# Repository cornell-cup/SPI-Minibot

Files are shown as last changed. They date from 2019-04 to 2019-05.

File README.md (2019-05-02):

# SPI-Minibot
For SPI communication between Pi and Arduino (should support up to 4 devices) with new PCB design

HOW TO RUN:
You type into terminal
1. cd SPI-Minibot
2. python -c 'import SPI_test; SPI_test.claw()'

NOTE: change .claw() function to whatever function you want to run
(ex. shoulder(), left(),right(),fwd(),back(),armL() [stepper], armR()[also stepper]

SPI_1.ino refers to top arduino (Closest to the raspberry pi)
SPI_A2.ino referes to bottom arduino (closest to battery)

When loading Arduino (.ino) programs:
Connect USB to serial (USB to jumper cables) and run SPI_1.ino on the top arduino
and then connect the cable to the bottom arduino and run SPI_A2.ino on the bottom one. 

When cloning this Repo (If not already loaded on the Pi):
1. Make sure you have SPI enabled (easiest way is through the GUI in NOOBS so you can just go to configuration and enable)
      Otherwise on terminal do ifconfig and select the option for serial (I think option 6, will verify later)
2. Make sure you have SCL,SDA,CE0, and CE1 wires all connected

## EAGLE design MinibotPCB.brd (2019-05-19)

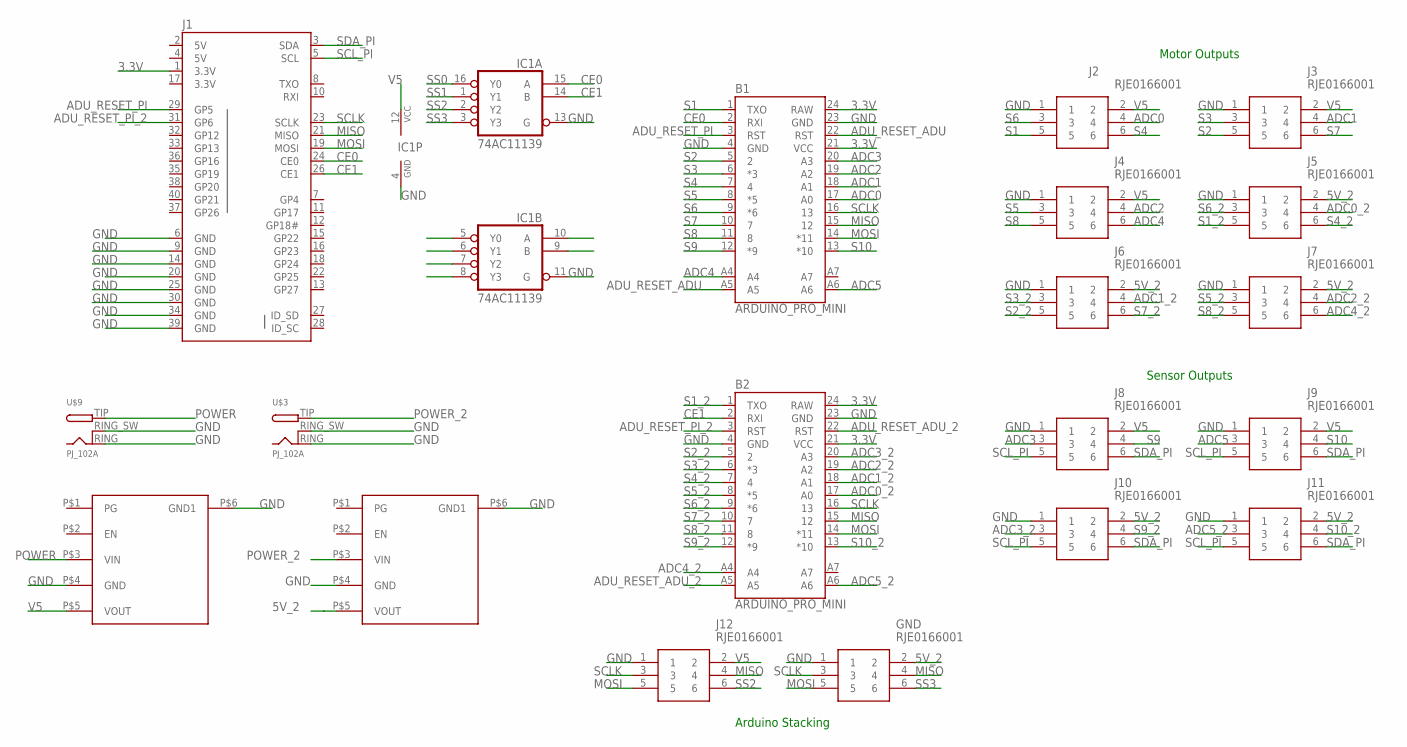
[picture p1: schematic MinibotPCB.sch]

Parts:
B1, B2: ARDUINO_PRO_MINI
GND: RJE0166001; RJE0166001_1
IC1: 74AC11139; DIL16
J1: RASPBERRYPI-40-PIN-GPIO_PTH_NO_SHROUD; 2X20
J2, J3, J4, J5, J6, J7, J8, J9, J10, J11, J12: RJE0166001; RJE0166001_1
U$1, U$2: D24V22F5
U$3, U$9: PJ_102A; PJ-102A

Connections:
3.3V: B1.21 (VCC), B1.24 (RAW), B2.21 (VCC), B2.24 (RAW), J1.1 (3.3V), J1.17 (3.3V)
5V: J1.2 (5V), J1.4 (5V)
5V_2: GND.2, J5.2, J6.2, J7.2, J10.2, J11.2, U$1.P$5 (VOUT)
ADC0: B1.17 (A0), J2.4
ADC0_2: B2.17 (A0), J5.4
ADC1: B1.18 (A1), J3.4
ADC1_2: B2.18 (A1), J6.4
ADC2: B1.19 (A2), J4.4
ADC2_2: B2.19 (A2), J7.4
ADC3: B1.20 (A3), J8.3
ADC3_2: B2.20 (A3), J10.3
ADC4: B1.A4, J4.6
ADC4_2: B2.A4, J7.6
ADC5: B1.A6, J9.3
ADC5_2: B2.A6, J11.3
ADU_RESET_ADU: B1.22 (RST), B1.A5
ADU_RESET_ADU_2: B2.22 (RST), B2.A5
ADU_RESET_PI: B1.3 (RST), J1.29 (GP5)
ADU_RESET_PI_2: B2.3 (RST), J1.31 (GP6)
CE0: B1.2 (RXI), IC1.15 (A), J1.24 (CE0)
CE1: B2.2 (RXI), IC1.14 (B), J1.26 (CE1)
GND: B1.4 (GND), B1.23 (GND), B2.4 (GND), B2.23 (GND), GND.1, IC1.4 (GND), IC1.11 (G), IC1.13 (G), J1.6 (GND), J1.9 (GND), J1.14 (GND), J1.20 (GND), J1.25 (GND), J1.30 (GND), J1.34 (GND), J1.39 (GND), J2.1, J3.1, J4.1, J5.1, J6.1, J7.1, J8.1, J9.1, J10.1, J11.1, J12.1, U$1.P$4 (GND), U$1.P$6 (GND1), U$2.P$4 (GND), U$2.P$6 (GND1), U$3.RING (GND), U$3.RING_SW (GNDBREAK), U$9.RING (GND), U$9.RING_SW (GNDBREAK)
MISO: B1.15 (12), B2.15 (12), GND.4, J1.21 (MISO), J12.4
MOSI: B1.14 (*11), B2.14 (*11), GND.5, J1.19 (MOSI), J12.5
POWER: U$2.P$3 (VIN), U$9.TIP (PWR)
POWER_2: U$1.P$3 (VIN), U$3.TIP (PWR)
S1: B1.1 (TXO), J2.5
S1_2: B2.1 (TXO), J5.5
S2: B1.5 (2), J3.5
S2_2: B2.5 (2), J6.5
S3: B1.6 (*3), J3.3
S3_2: B2.6 (*3), J6.3
S4: B1.7 (4), J2.6
S4_2: B2.7 (4), J5.6
S5: B1.8 (*5), J4.3
S5_2: B2.8 (*5), J7.3
S6: B1.9 (*6), J2.3
S6_2: B2.9 (*6), J5.3
S7: B1.10 (7), J3.6
S7_2: B2.10 (7), J6.6
S8: B1.11 (8), J4.5
S8_2: B2.11 (8), J7.5
S9: B1.12 (*9), J8.4
S9_2: B2.12 (*9), J10.4
S10: B1.13 (*10), J9.4
S10_2: B2.13 (*10), J11.4
SCLK: B1.16 (13), B2.16 (13), GND.3, J1.23 (SCLK), J12.3
SCL_PI: J1.5 (SCL), J8.5, J9.5, J10.5, J11.5
SDA_PI: J1.3 (SDA), J8.6, J9.6, J10.6, J11.6
SS0: IC1.16 (Y0)
SS1: IC1.1 (Y1)
SS2: IC1.2 (Y2), J12.6
SS3: GND.6, IC1.3 (Y3)
V5: IC1.12 (VCC), J2.2, J3.2, J4.2, J8.2, J9.2, J12.2, U$2.P$5 (VOUT)

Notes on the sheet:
Arduino Stacking
Sensor Outputs
Motor Outputs

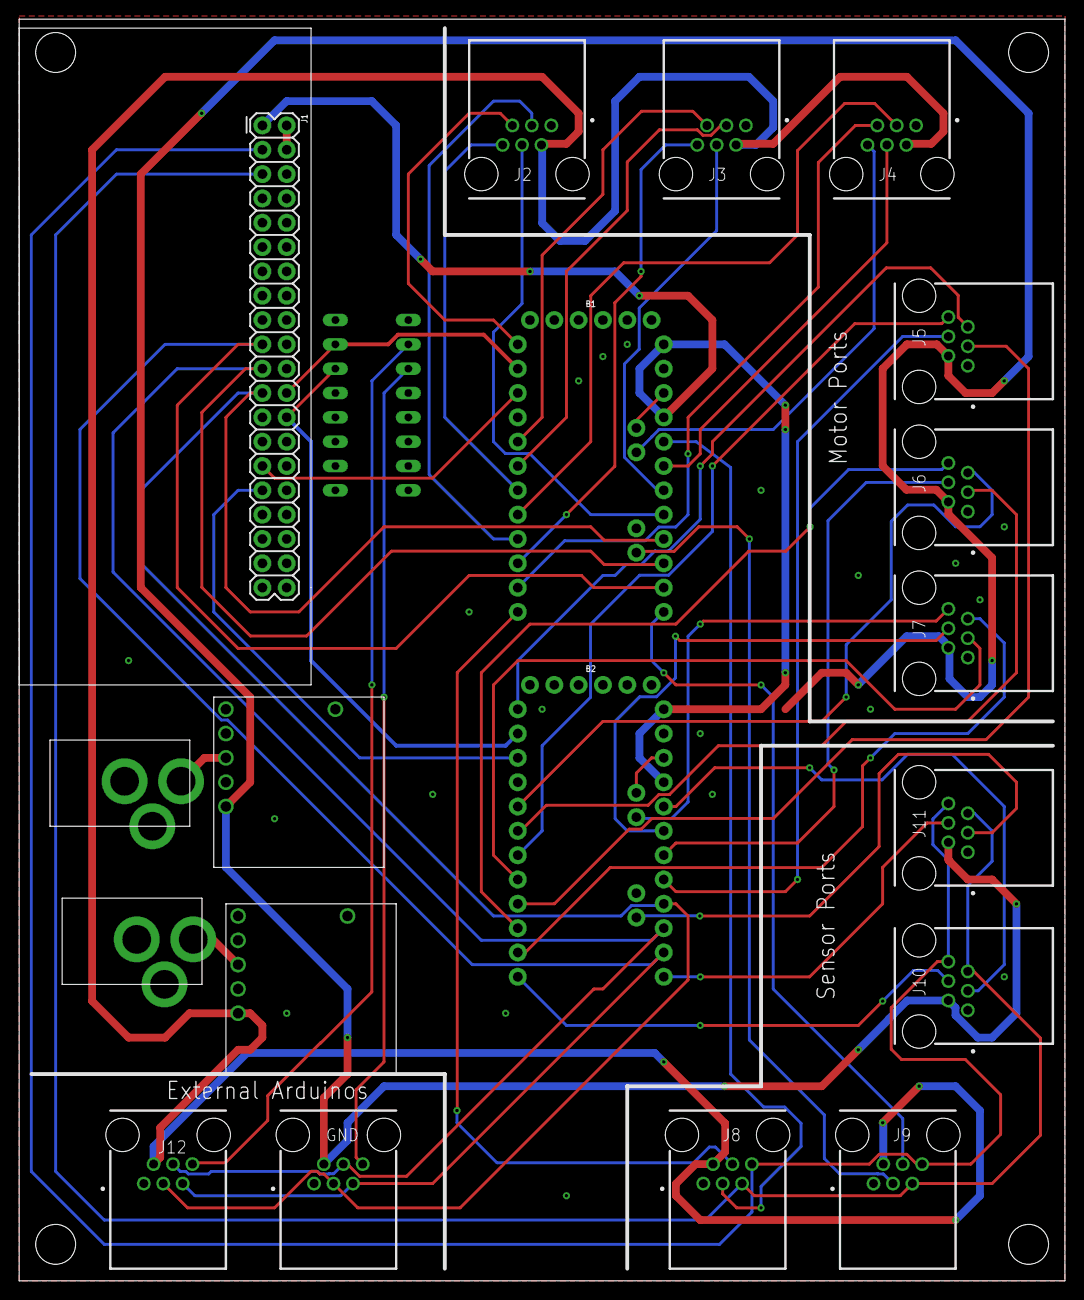
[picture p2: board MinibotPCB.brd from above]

Board: 2 copper layers, 109.2 x 131.8 mm, 20 parts (1 on the bottom side), 52 nets.

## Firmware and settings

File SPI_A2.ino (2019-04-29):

#include <SPI.h>
#include <Servo.h>
#include <Stepper.h>

const int stepsPerRevolution = 2038;// change this to fit the number of steps per revolution
// for your motor

// initialize the stepper library on pins 8 through 11:

Stepper stepper(stepsPerRevolution, A1, 7, 3, 2);
Stepper rstepper(stepsPerRevolution, 2,3,7,A1);
Stepper stepper2(stepsPerRevolution, A2, A4, 5, 8);
Stepper rstepper2(stepsPerRevolution, 8,5,A4,A2);

int stepCount = 0;         // number of steps the motor has taken

Servo myservo;

int val;
char buff [50];
volatile byte indx;
volatile boolean process;
//int  interruptPin = 10;
//int motorPin1 = 2;
//int motorPin2 = 3;
//int motorPin3 = 8;
//int motorPin4 = 5;
void setup() {
  // put your setup code here, to run once:
  Serial.begin(115200);
  myservo.attach(6);//servo pin
  pinMode(MISO,OUTPUT); //init spi
  pinMode(3,OUTPUT);
  //Init DC pins
//  pinMode(motorPin1, OUTPUT);
//  pinMode(motorPin2, OUTPUT);
//  pinMode(motorPin3, OUTPUT);
//  pinMode(motorPin4, OUTPUT);
  pinMode(20,OUTPUT);
  pinMode(22,OUTPUT);
  SPCR |= bit (SPE); // slave control register
  indx = 0; //buffer empty
  process = false;
  
//  pinMode(interruptPin,INPUT);
//  int val = digitalRead(interruptPin);
  //if (!val)
    //Serial.println ("wtf");
  delay(1000);
  SPI.attachInterrupt();
 // attachInterrupt(digitalPinToInterrupt(interruptPin), tester, LOW); //enable interrupt
  //val = 1;
  //Serial.print(val);
  }

ISR (SPI_STC_vect) //SPI Interrupt Service Routine
//void tester() 
{
 // digitalWrite(3,1);
  //Serial.println("work");
  byte c = SPDR; //read byte from SPI data register
  if (indx < sizeof (buff) - 1) 
    buff [indx++] = c;// save data in the next index in the array buff
 // if (c == '\r') //check for the end of the word
    process = true;
  
}  
void loop() {
//
//digitalWrite(motorPin1, LOW);
//          digitalWrite(motorPin2, LOW);
//          digitalWrite(motorPin3, LOW);
//          digitalWrite(motorPin4, LOW);  
//   put your main code here, to run repeatedly:

//  stepper.step(1);
//  Serial.print("steps:");
//  Serial.println(stepCount);
//  stepCount++;
//  delayMicroseconds(2000);


  if (process) {
    buff[indx] = 0;
    process = false; //reset flag
    digitalWrite(3,0);
 //   Serial.println("work");
    Serial.print(buff); //print to serial monitor
    int i = 0;
    if (i < sizeof(buff)) {
      switch(buff[i]) {
        case 'S' : //servo (shoulder())
         // for (int j = 0; j <20; j++) {
            myservo.write(140);
            delay(300);
            myservo.write(90);
            delay(300);
            Serial.print("w");
        //  }
          break;   
        case 'T' : //stepper
         for (int j = 0; j <820; j++) {
           stepper.step(1);
           Serial.print("steps:");
           Serial.println(stepCount);
           stepCount++;
           delayMicroseconds(2000);
         }
         for (int j = 0; j <820; j++) {
           rstepper.step(1);
           Serial.print("steps:");
           Serial.println(stepCount);
           stepCount++;
           delayMicroseconds(2000);
         }
         break;
         case 'O' : // Other stepper
         for (int j = 0; j <820; j++) {
           stepper2.step(1);
           Serial.print("steps:");
           Serial.println(stepCount);
           stepCount++;
           delayMicroseconds(2000);
         }
         for (int j = 0; j <820; j++) {
           rstepper2.step(1);
           Serial.print("steps:");
           Serial.println(stepCount);
           stepCount++;
           delayMicroseconds(2000);
         }
         break;
        default:
          i++;
          break; 
        
      }
    }
  }

    //SPDR = data  //sends value to master via SPDR
    indx = 0; //reset button to zero
}
 

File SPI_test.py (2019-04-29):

import binascii
import spidev
import time

spi = spidev.SpiDev()

def setSlave(PiBus):
  device = 0
  bus = PiBus
  spi.open(device,bus)
  spi.mode = 0
  spi.max_speed_hz = 115200

def transmit(message):  
  try:
    while True:
      print (message)
      tx = spi.writebytes([message])
      time.sleep(10)
      rx = spi.readbytes(2)
      print('Read: 0x(0)'.format(binascii.hexlify(bytearray(rx))))
  finally:
    spi.close()


def fwd():
  setSlave(0)
  cmd = ord('F')
  #print b
  print cmd
  transmit(cmd)
  
def back():
  setSlave(0)
  cmd = ord('B')
  #print b
  print cmd
  transmit(cmd)          

def left():
  setSlave(0)
  cmd = ord('L')
  #print b
  print cmd
  transmit(cmd) 
          
def right():
  setSlave(0)
  cmd = ord('R')
  #print b
  print cmd
  transmit(cmd)     
    
def claw():
  setSlave(0)
  cmd = ord('C')
  #print b
  print cmd
  transmit(cmd)

def armL():
  setSlave(1)
  cmd = ord('T')
  #print b
  print cmd
  transmit(cmd)            
          
def armR():
  setSlave(1)
  cmd = ord('O')
  #print b
  print cmd
  transmit(cmd)
   
def shoulder():
  setSlave(1)
  cmd = ord('S')
  #print b
  print cmd
  transmit(cmd)            

  

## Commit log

2019-04-27 Added test file for SPI
2019-04-28 SPI working format wrong
    [SPI_test.py]
2019-04-28 SPI working
2019-04-29 Use for top arduino
2019-04-29 Use for arduino 2 (bottom)
2019-05-19 Added PCB files to show schematics
    [Cup4Lyfe.brd, Cup4Lyfe.sch]
